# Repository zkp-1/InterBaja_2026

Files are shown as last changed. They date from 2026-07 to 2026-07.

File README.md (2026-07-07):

# InterBaja_2026
Repo of Electrical Team for the pre-existing vehicle electrical system design from scratch.

**ACKNOWLEDGEMENTS.md** recognizes those members and volunteers whose performance was exemplary.

**DOCUMENTATION.md** has an overview and documentation summary of our final design.

On the main branch there are the two final schematics, alongside the folder containing the KiCAD project. Read the documentation for clarity between these different revisions.

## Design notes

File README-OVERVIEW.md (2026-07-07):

# InterBaja_2026
Repo of Electrical Team for the pre-existing vehicle electrical system design from scratch.

# Electrical System Retrofit for Existing BAJA Vehicle

## System Overview
This repository contains the electrical system design and schematics for retrofitting a legacy BAJA competition car from the Interamerican University of Puerto Rico (Bayamon Campus). The vehicle originally featured no onboard electrical system. The new designed architecture provides reliable power distribution, relay-driven load switching, and essential safety measures.

Due to current hardware availability and specific application requirements, the system is split into two schematic variants:
1. **[Final System Design.pdf] (Current Implementation):** Operates entirely on pre-charged onboard batteries[cite: 2].
2. **[Final System Design (with Alternator).pdf] (Alternate Implementation):** Includes an integrated charging circuit (Alternator -> Filtered Rectifier -> Voltage Regulator -> Battery Terminals) which can be implemented, given that an alternator can be .

## Power Delivery & Management

* **Dual-Battery Configuration:** The system utilizes two 12V 12Ah (or bigger Amp-hour capacity) batteries wired in parallel. This upgrade from a single battery was necessary to increase the total Amp-hour (Ah) capacity of the system, ensuring sustained operation without an active charging source.
* **Magneto Isolation:** During initial testing, tapping the engine's built-in magneto as an AC source overloaded the circuit. Completing the circuit by attaching the ground to the AC pin of the bridge rectifier caused severe voltage sag, resulting in a loss of engine spark and subsequent stalling. Therefore, the magneto is strictly isolated and dedicated solely to the car's ignition system. 
* **Charging State:** In the current "Main Design" configuration, there is no self-charging capability. The batteries must be fully charged prior to operational use. The only exception, is when using the "Main Design with Alternator" Variant which provides self-charging and should also run without batteries.

## Switching, Logic, & Loads

* **Safety Cut-offs:** A main kill switch is integrated to shut down the main bus immediately in the event of an emergency or to disable the +12V bus during testing. 
* **Relay Logic:** Standard SPST-NO relays are used to reliably control the load distribution for the brake lights and other auxiliary systems.
* **Load Provisions (DNP):** The system design includes the necessary wiring and relay logic for a Reverse Light and a designated "Third Load". These are currently marked as DNP (Do Not Populate) with an 'X' as they are unused in the present application, but the infrastructure remains for future plug-and-play capability.
* **Relay Flyback protection:** Flyback and protection diodes across the system are standard diodes or typical power diodes to safely handle inductive loads. These should at least be rated for 1A.

## Roadmap & Future Improvements

The current electrical framework provides a solid, modular foundation for the following expansions:
* **Active Charging System:** Installing a belt-driven alternator to utilize the **[Final System Design (with Alternator).pdf]** schematic, enabling self-charging.
* **Microcontroller Integration:** Adding an onboard MCU (e.g., Arduino, Teensy, or ESP32) to process and transmit vehicle telemetry.
* **Instrumentation:** 
  * RPM Gauge utilizing a Hall Effect sensor on the drivetrain/engine.
  * Fuel level sensor and dedicated dashboard gauge.
  * System Voltage monitor to track battery depletion or system voltage during operation.

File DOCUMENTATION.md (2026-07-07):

# Electrical System Retrofit for Existing BAJA Vehicle

## System Overview
This repository contains the electrical system design and schematics for retrofitting a legacy BAJA competition car from the Interamerican University of Puerto Rico (Bayamon Campus). The vehicle originally featured no onboard electrical system. The new designed architecture provides reliable and solid power distribution alongside relay-driven load switching, and essential safety measures.

Due to hardware availability at the time of implementation and deadlines, the system is split into two schematic variants:
1. **[Final System Design.pdf] (Current Implementation):** Operates entirely on pre-charged onboard batteries.
2. **[Final System Design (with Alternator).pdf] (Alternate Implementation):** Includes an integrated charging circuit (Alternator -> Filtered Rectifier -> Voltage Regulator -> Battery Terminals) which can be implemented, given that an alternator can be provided.

## Power Delivery & Management

* **Dual-Battery Configuration:** The system utilizes two 12V 12Ah (or bigger Amp-hour capacity) batteries wired in parallel. This upgrade from a single battery was necessary to increase the total Amp-hour (Ah) capacity of the system, ensuring sustained operation without an active charging source.
* **Magneto Isolation:** During initial testing, tapping the engine's built-in magneto as an AC source overloaded the circuit. Completing the circuit by attaching the ground to the AC pin of the bridge rectifier caused severe voltage sag, resulting in a loss of engine spark and subsequent stalling. Therefore, the magneto is strictly isolated and dedicated solely to the car's ignition system. 
* **Charging State:** In the current "Main Design" configuration, there is no self-charging capability. The batteries must be fully charged prior to operational use. The only exception, is when using the "Main Design with Alternator" Variant which provides self-charging and should also run without batteries.

## Switching, Logic, & Loads

* **Safety Cut-offs:** A main kill switch is integrated to shut down the main bus immediately in the event of an emergency or to disable the +12V bus during testing. 
* **Relay Logic:** Standard SPST-NO relays are used to reliably control the load distribution for the brake lights and other auxiliary systems.
* **Load Provisions (DNP):** The system design includes the necessary wiring and relay logic for a Reverse Light and a designated "Third Load". These are currently marked as DNP (Do Not Populate) with an 'X' as they are unused in the present application, but the infrastructure remains for future plug-and-play capability.
* **Relay Flyback protection:** Flyback and protection diodes across the system are standard diodes or typical power diodes to safely handle inductive loads. These should at least be rated for 1A.

## Roadmap & Future Improvements

The current electrical framework provides a solid, modular foundation for the following expansions:
* **Active Charging System:** Installing a belt-driven alternator to utilize the **[Final System Design (with Alternator).pdf]** schematic, enabling self-charging.
* **Microcontroller Integration:** Adding an onboard MCU (e.g., Arduino, Teensy, or ESP32) to process and transmit vehicle telemetry.
* **Instrumentation:** 
  * RPM Gauge utilizing a Hall Effect sensor on the drivetrain/engine.
  * Fuel level sensor and dedicated dashboard gauge.
  * System Voltage monitor to track battery depletion or system voltage during operation.

## Notes

If this information is useful, feel free to use it. Although we wouldn't mind a little credit, since this design was made from the blood, sweat and tears of a couple of EE students haha. Referencing our team or the electrical leader (main collaborator) and linking this site should be fine.

If you have any questions, my profile should have an email where you can inquire further.

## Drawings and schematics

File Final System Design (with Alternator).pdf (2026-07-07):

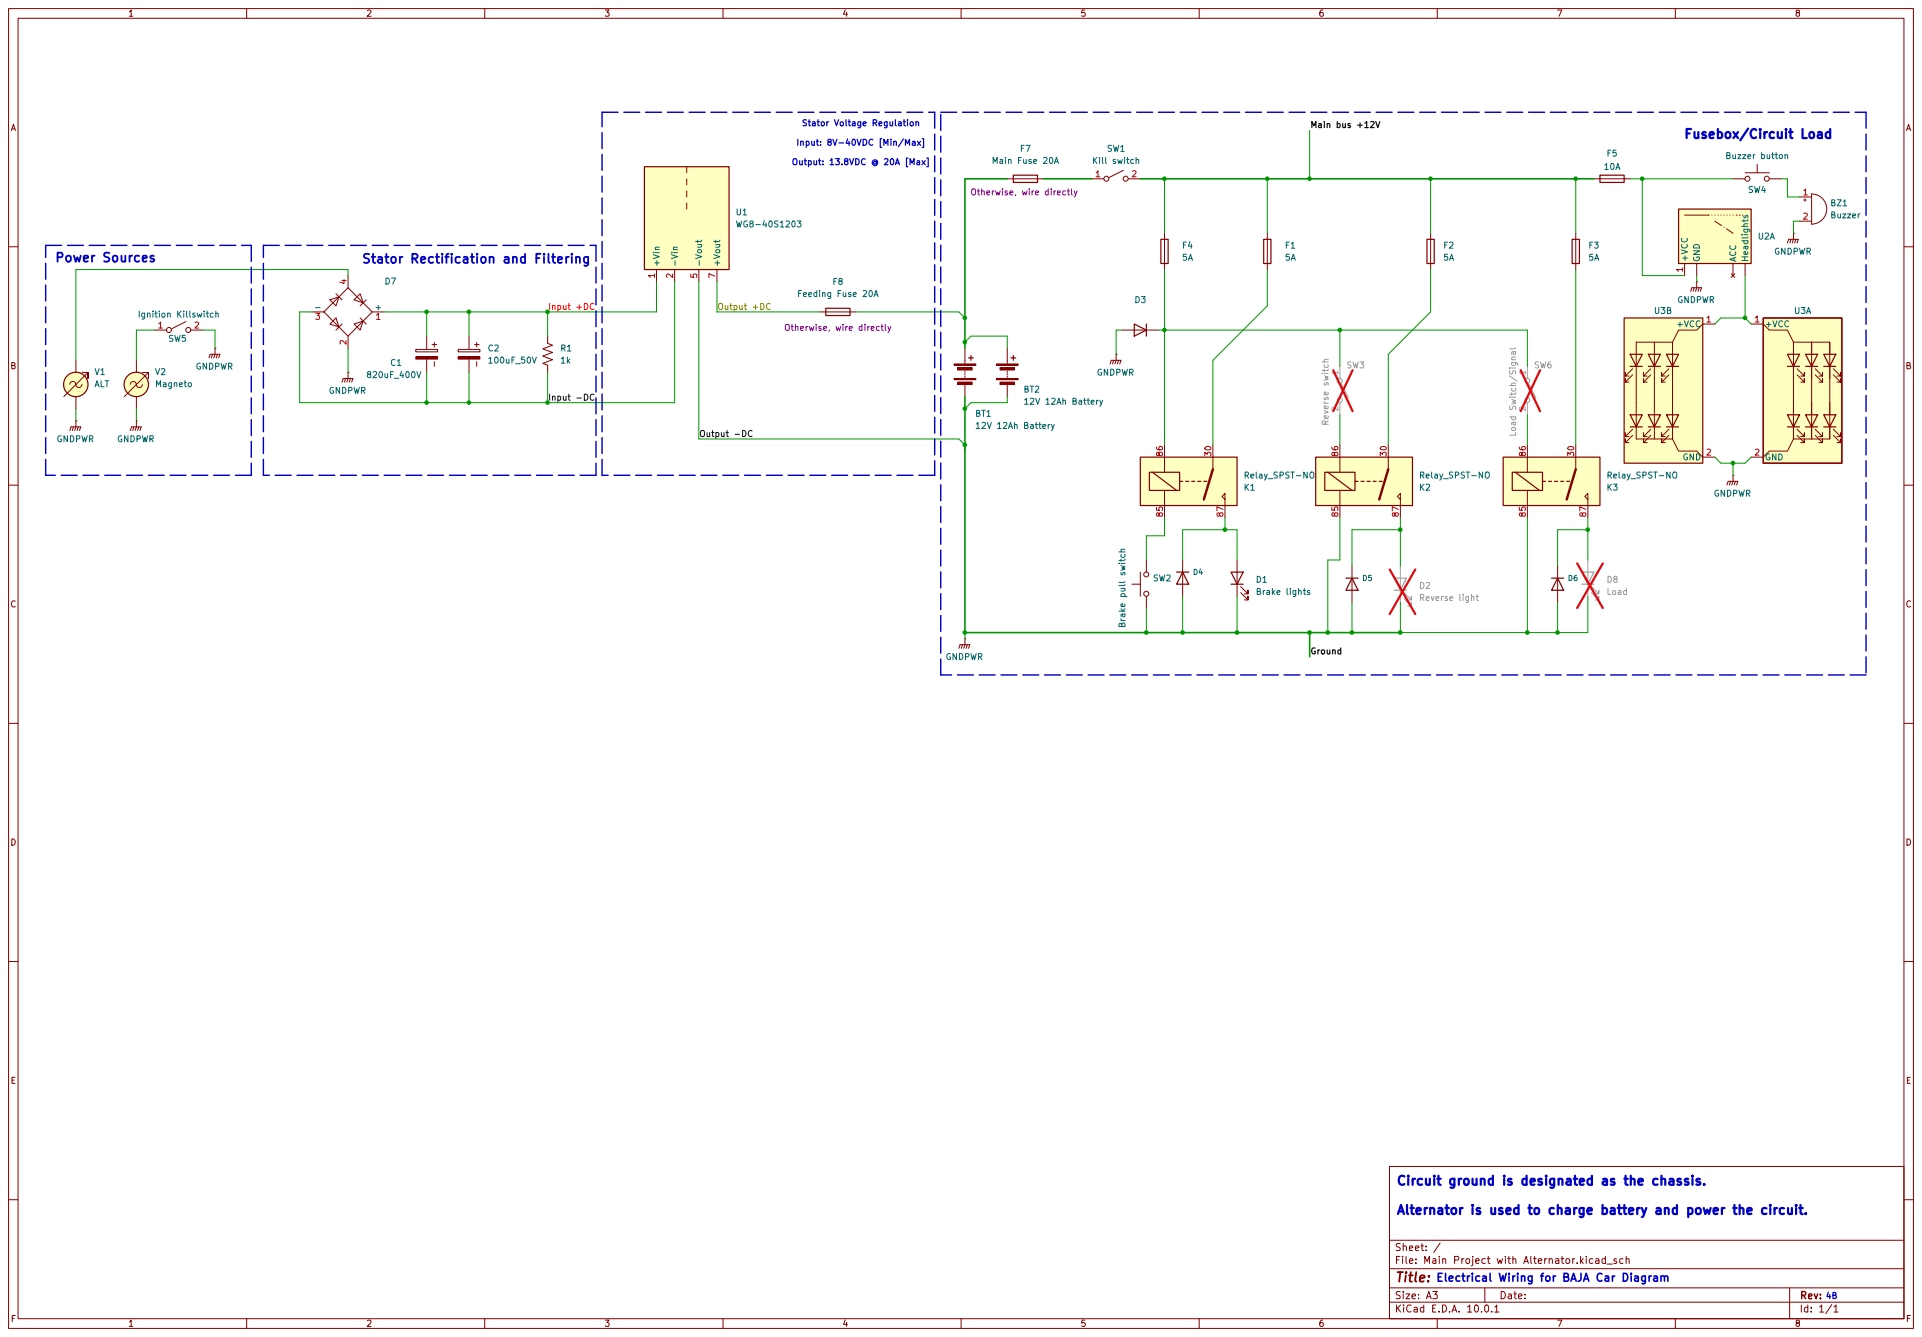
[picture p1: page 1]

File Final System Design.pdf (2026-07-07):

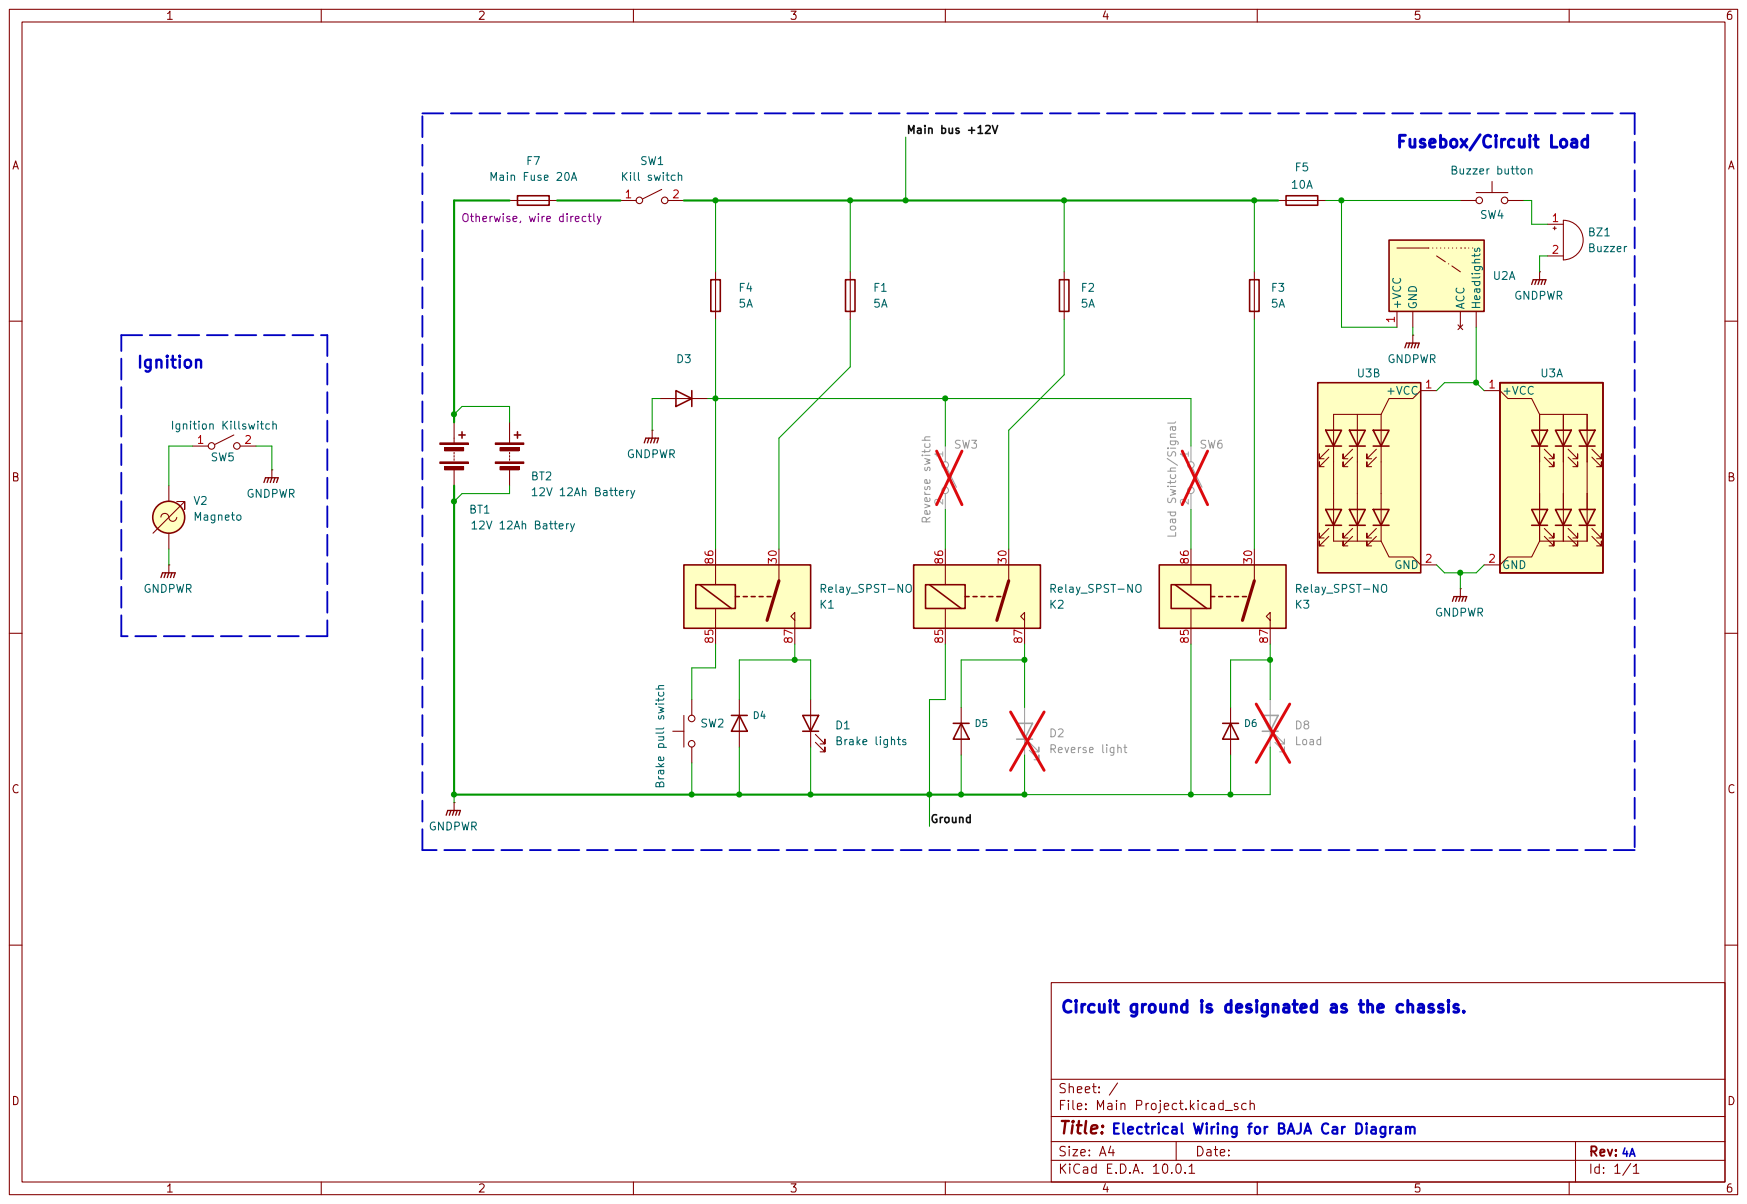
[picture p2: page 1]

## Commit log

2026-03-25 Initial Design KiCad project
    Project files from 25th of March meeting.
    [Main Project.kicad_pcb, Main Project.kicad_sch]
2026-05-30 Revision 2
    - Added Stator and voltage regulator to schematic
    - Switched relay logic to match the prewired fusebox
    - Added Headlights
    - Changed buzzer logic according to project constraints
    [Main Project.kicad_sch]
2026-06-03 Rev 2 file update
    - Added Second design to match intended real assembly
    [Main Project.kicad_sch]
2026-07-07 Final Design Upload
    - Separated designs:
    1. Main Design - Has no self-charging power source. This is due to a lack of alternator in application, and the magneto can only output a couple of watts (1W being conservative).
    2. Main Design w/ Alternator - Main Design + [Alternator -> Filtered Rectifier -> Voltage Regulator -> ±Battery terminals]
    General Changelog:
    - Added second battery in parallel to main battery due to low Ah rating.
    - Diodes have been changed from 1N4148 to a typical Diode (Safety Load measure).
    - Design is ready for Reverse Light and a third load, but are placed as DNP due to being unused in the application of said design.
    - Changed "Stator" into Magneto; Left Magneto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
    [Main Project with Alternator.kicad_sch]
2026-07-07 Schematics to Main branch
    - Added schematics to main branch directly.
